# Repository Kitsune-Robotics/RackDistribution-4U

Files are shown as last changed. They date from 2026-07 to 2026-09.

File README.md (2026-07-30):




# RackDistribution-4U

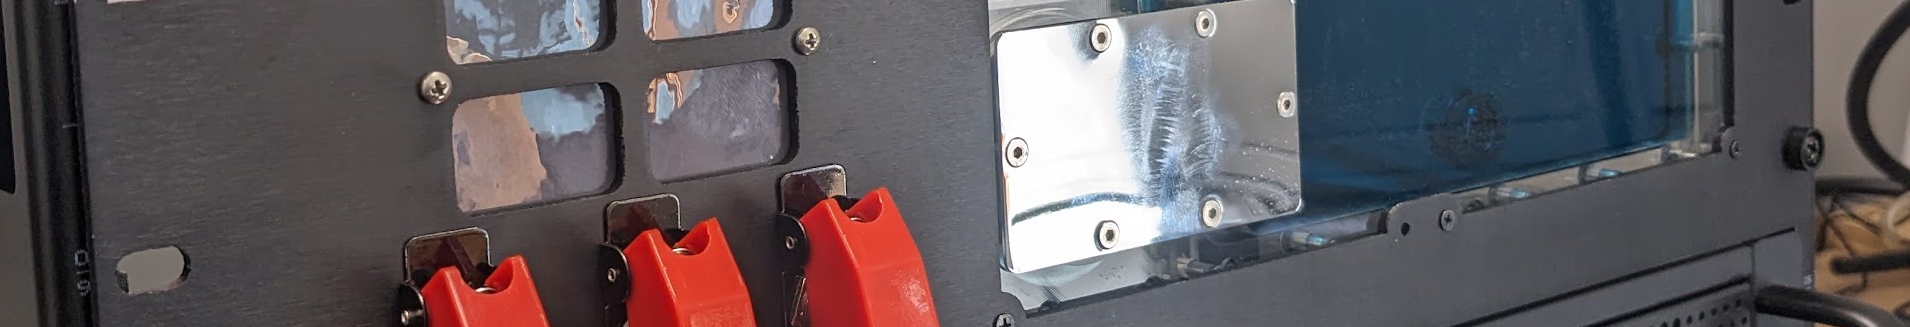
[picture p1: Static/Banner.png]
Banner


This repo contains all the firmware and hardware for the RackDistribution-4U.
If you're looking for the latest docs/builds, see our [Releases Page](https://github.com/Kitsune-Robotics/RackDistribution-4U/releases).

# Getting Started

First, clone this repo (and optionally checkout a branch)

```shell
git clone https://github.com/Kitsune-Robotics/RackDistribution-4U.git
cd RackDistribution-4U
```

# Init Submodules

Some libraries and resources are included as submodules, run the following
command to initialize them before opening the main sch

(If you get a missing library error, make sure to do this)

```shell
git submodule update --init --recursive
```

## Project Layout

If you want to use this project template for yourself, you can find it [here!](https://github.com/Kitsune-Robotics/Project-Template)

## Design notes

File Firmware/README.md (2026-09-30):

# Rack Distribution 4U firmware

Built with the [Pico SDK](https://github.com/raspberrypi/pico-sdk) for an RP2040.
FreeRTOS plus the WS2812 PIO driver for the light panel.

## To build

`pico_sdk_import.cmake` will pull the SDK if you don't already have `PICO_SDK_PATH`.

```shell
git submodule update --init Firmware/lib/FreeRTOS-Kernel
mkdir build
cd build
cmake ..
make
```

## To load

The running firmware is a composite USB device: RackDistribution HID (`1209:0001`), CDC, and a `RACKDIST` drive. Copy a UF2 onto that drive to update, or:

From the build directory:

```shell
../aquacomputer/pico-load rack_distribution.uf2
```

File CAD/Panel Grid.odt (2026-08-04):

STANDBY | COOLDOWN
A LITTLE HOT | CONTROL
LOW COOLANT | LOW PUMP SPEED
LOW FLOW | LOW FAN SPEED

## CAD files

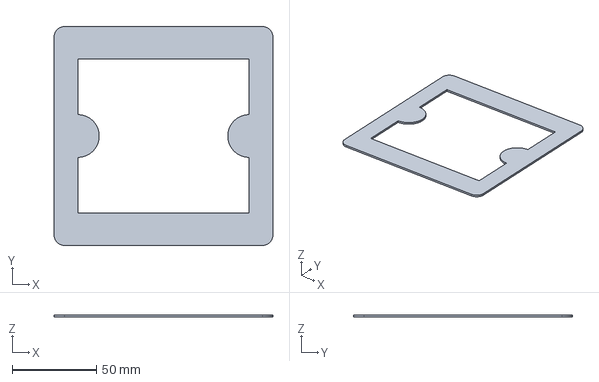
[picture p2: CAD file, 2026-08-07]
CAD/Solder Stencil.FCStd
130.0 x 130.0 x 1.40 mm

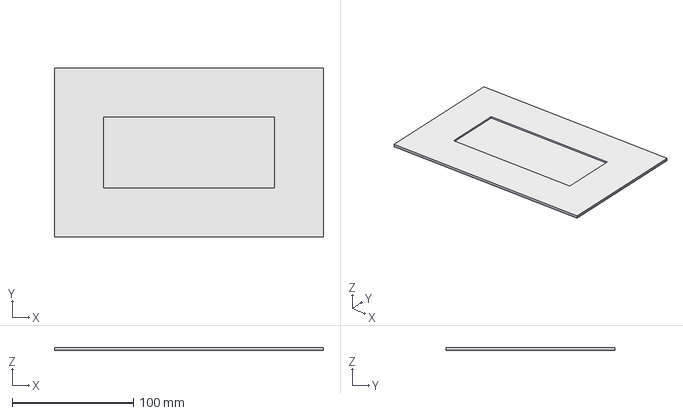
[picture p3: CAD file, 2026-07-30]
Hardware/LightPanel/Stencils/SolderMaskStencil.FCStd
222.2 x 139.7 x 2.60 mm

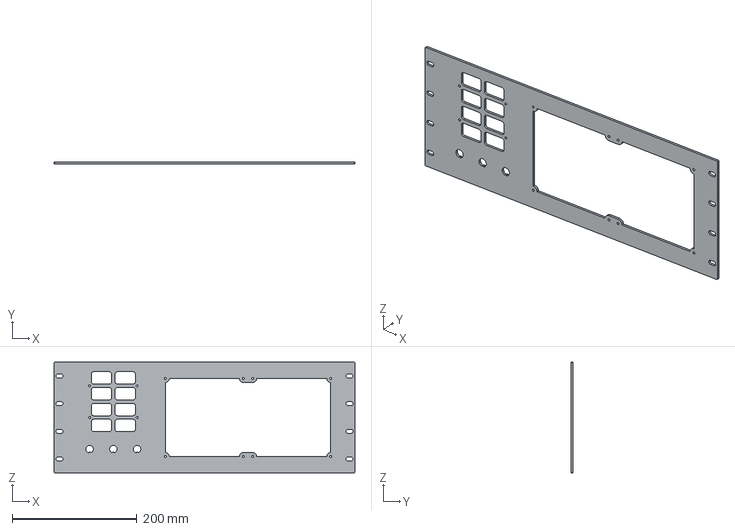
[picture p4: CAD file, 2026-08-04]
CAD/WaterCoolingRack-Sheet Metal.step
482.5 x 3.18 x 177.8 mm

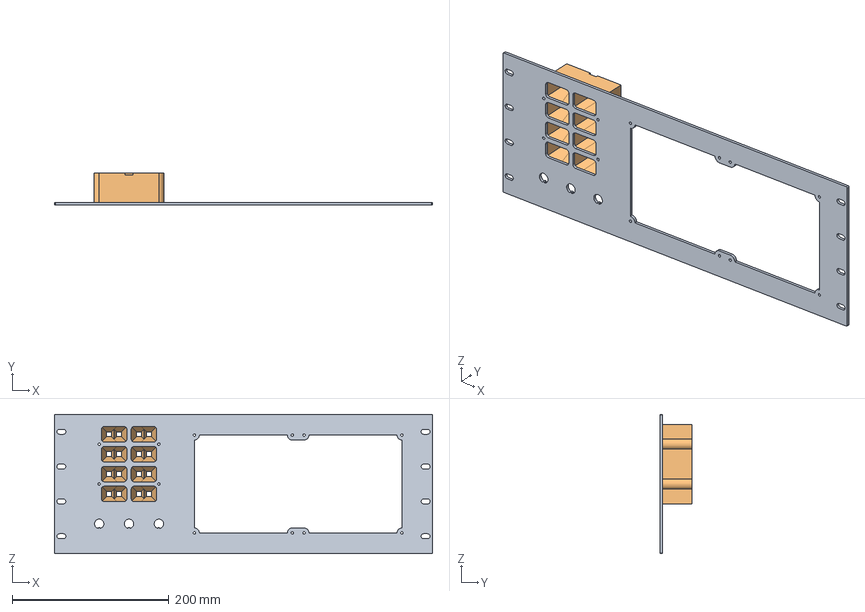
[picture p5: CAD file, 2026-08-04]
CAD/WaterCoolingRack.FCStd
482.5 x 41.3 x 177.8 mm
Sheet Metal
Light Gaurd

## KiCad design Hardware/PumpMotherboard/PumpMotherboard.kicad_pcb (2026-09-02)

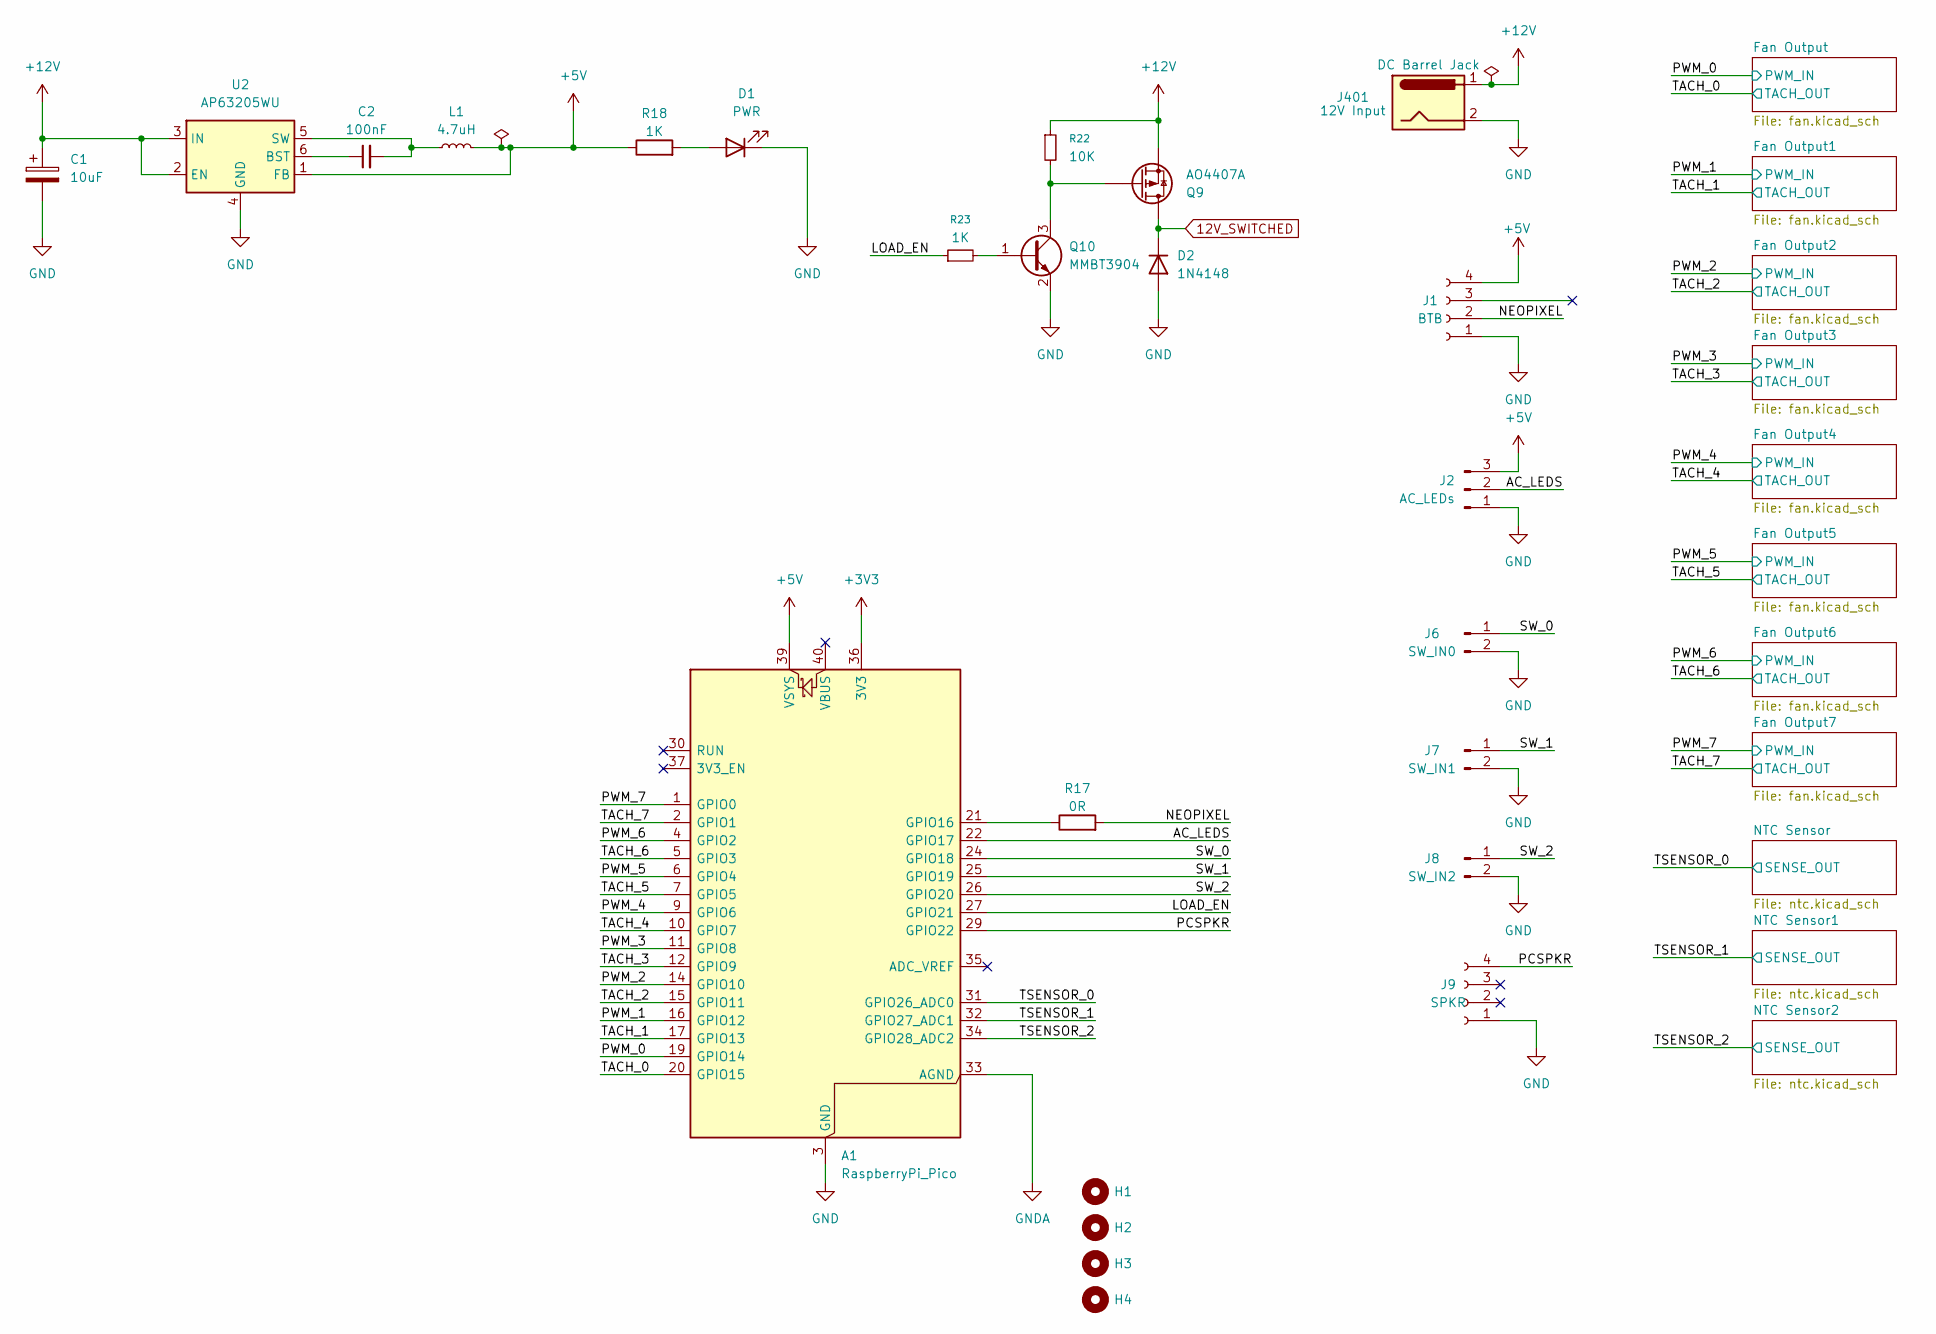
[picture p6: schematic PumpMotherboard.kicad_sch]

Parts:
A1: RaspberryPi_Pico; RaspberryPi_Pico_Common_SMD
C1: 10uF; CP_Elec_4x3
C2: 100nF; C_0805_2012Metric
D1: PWR; LED_0805_2012Metric
D2: 1N4148; D_DO-35_SOD27_P7.62mm_Horizontal
H1, H2, H3, H4: MountingHole; MountingHole_4.3mm_M4
J1: BTB; PinSocket_1x04_P2.54mm_Vertical
J2: AC_LEDs; JST_XH_B3B-XH-A_1x03_P2.50mm_Vertical
J6: SW_IN0; JST_XH_B2B-XH-A_1x02_P2.50mm_Vertical
J7: SW_IN1; JST_XH_B2B-XH-A_1x02_P2.50mm_Vertical
J8: SW_IN2; JST_XH_B2B-XH-A_1x02_P2.50mm_Vertical
J9: SPKR; PinHeader_1x04_P2.54mm_Vertical
J401: 12V Input; BarrelJack_GCT_DCJ200-10-A_Horizontal
L1: 4.7uH; L_APV_ANR4012; LCSC# C467061
Q9: AO4407A; SOIC-8_5.3x5.3mm_P1.27mm
Q10: MMBT3904; SOT-23
R17: 0R; R_0805_2012Metric
R18, R23: 1K; R_0805_2012Metric
R22: 10K; R_0805_2012Metric
U2: AP63205WU; TSOT-23-6; LCSC# C2071056

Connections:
12V_SWITCHED: D2.1 (K), Q9.5 (D), Q9.6 (D), Q9.7 (D), Q9.8 (D); also elsewhere on the board
+3V3: A1.36 (3V3); also elsewhere on the board
+5V: A1.39 (VSYS), J1.4, J2.3, L1.2, R18.1, U2.1 (FB)
+12V: C1.1, J401.1, Q9.1 (S), Q9.2 (S), Q9.3 (S), R22.1, U2.2 (EN), U2.3 (IN)
/AC_LEDS: A1.22 (GPIO17), J2.2
/LOAD_EN: A1.27 (GPIO21), R23.1
/NEOPIXEL: J1.2, R17.2
/PCSPKR: A1.29 (GPIO22), J9.4
/PWM_0: A1.19 (GPIO14); also elsewhere on the board
/PWM_1: A1.16 (GPIO12); also elsewhere on the board
/PWM_2: A1.14 (GPIO10); also elsewhere on the board
/PWM_3: A1.11 (GPIO8); also elsewhere on the board
/PWM_4: A1.9 (GPIO6); also elsewhere on the board
/PWM_5: A1.6 (GPIO4); also elsewhere on the board
/PWM_6: A1.4 (GPIO2); also elsewhere on the board
/PWM_7: A1.1 (GPIO0); also elsewhere on the board
/SW_0: A1.24 (GPIO18), J6.1
/SW_1: A1.25 (GPIO19), J7.1
/SW_2: A1.26 (GPIO20), J8.1
/TACH_0: A1.20 (GPIO15); also elsewhere on the board
/TACH_1: A1.17 (GPIO13); also elsewhere on the board
/TACH_2: A1.15 (GPIO11); also elsewhere on the board
/TACH_3: A1.12 (GPIO9); also elsewhere on the board
/TACH_4: A1.10 (GPIO7); also elsewhere on the board
/TACH_5: A1.7 (GPIO5); also elsewhere on the board
/TACH_6: A1.5 (GPIO3); also elsewhere on the board
/TACH_7: A1.2 (GPIO1); also elsewhere on the board
/TSENSOR_0: A1.31 (GPIO26_ADC0); also elsewhere on the board
/TSENSOR_1: A1.32 (GPIO27_ADC1); also elsewhere on the board
/TSENSOR_2: A1.34 (GPIO28_ADC2); also elsewhere on the board
GND: A1.3 (GND), A1.8 (GND), A1.13 (GND), A1.18 (GND), A1.23 (GND), A1.28 (GND), A1.38 (GND), C1.2, D1.1 (K), D2.2 (A), J1.1, J2.1, J6.2, J7.2, J8.2, J9.1, J401.2, Q10.2 (E), U2.4 (GND); also elsewhere on the board
GNDA: A1.33 (AGND); also elsewhere on the board
unnamed: A1.21 (GPIO16), R17.1
unnamed: D1.2 (A), R18.2
unnamed: Q10.1 (B), R23.2
unnamed: Q9.4 (G), Q10.3 (C), R22.2
unnamed: C2.1, U2.6 (BST)
unnamed: C2.2, L1.1, U2.5 (SW)

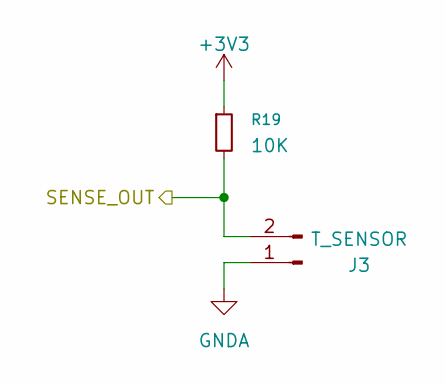
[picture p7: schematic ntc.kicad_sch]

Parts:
J3: T_SENSOR; PinHeader_1x02_P2.54mm_Vertical
R19: 10K; R_0805_2012Metric

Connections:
+3V3: R19.1; also elsewhere on the board
/TSENSOR_0: J3.2, R19.2; also elsewhere on the board
GNDA: J3.1; also elsewhere on the board

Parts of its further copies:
J4, J5: T_SENSOR; PinHeader_1x02_P2.54mm_Vertical
R20, R21: 10K; R_0805_2012Metric

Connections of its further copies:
+3V3: R20.1, R21.1; also elsewhere on the board
/TSENSOR_1: J4.2, R20.2; also elsewhere on the board
/TSENSOR_2: J5.2, R21.2; also elsewhere on the board
GNDA: J4.1, J5.1; also elsewhere on the board

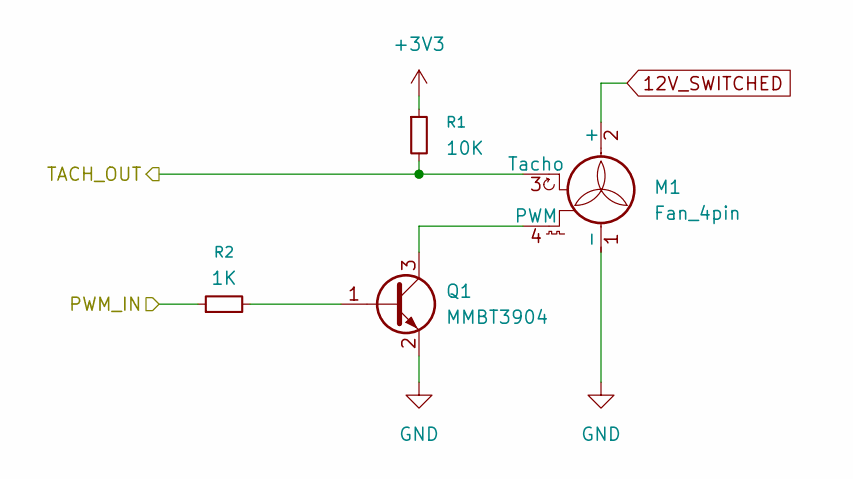
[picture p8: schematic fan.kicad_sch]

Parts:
M1: Fan_4pin; FanPinHeader_1x04_P2.54mm_Vertical; LCSC# C240840
Q1: MMBT3904; SOT-23
R1: 10K; R_0805_2012Metric
R2: 1K; R_0805_2012Metric

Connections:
12V_SWITCHED: M1.2 (+); also elsewhere on the board
+3V3: R1.1; also elsewhere on the board
/PWM_0: R2.1; also elsewhere on the board
/TACH_0: M1.3 (Tacho), R1.2; also elsewhere on the board
GND: M1.1 (-), Q1.2 (E); also elsewhere on the board
unnamed: M1.4 (PWM), Q1.3 (C)
unnamed: Q1.1 (B), R2.2

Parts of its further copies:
M2, M3, M4, M5, M6, M7, M8: Fan_4pin; FanPinHeader_1x04_P2.54mm_Vertical; LCSC# C240840
Q2, Q3, Q4, Q5, Q6, Q7, Q8: MMBT3904; SOT-23
R3, R5, R7, R9, R11, R13, R15: 1K; R_0805_2012Metric
R4, R6, R8, R10, R12, R14, R16: 10K; R_0805_2012Metric

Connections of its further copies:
12V_SWITCHED: M2.2 (+), M3.2 (+), M4.2 (+), M5.2 (+), M6.2 (+), M7.2 (+), M8.2 (+); also elsewhere on the board
+3V3: R4.1, R6.1, R8.1, R10.1, R12.1, R14.1, R16.1; also elsewhere on the board
/PWM_1: R3.1; also elsewhere on the board
/PWM_2: R5.1; also elsewhere on the board
/PWM_3: R7.1; also elsewhere on the board
/PWM_4: R9.1; also elsewhere on the board
/PWM_5: R11.1; also elsewhere on the board
/PWM_6: R13.1; also elsewhere on the board
/PWM_7: R15.1; also elsewhere on the board
/TACH_1: M2.3 (Tacho), R4.2; also elsewhere on the board
/TACH_2: M3.3 (Tacho), R6.2; also elsewhere on the board
/TACH_3: M4.3 (Tacho), R8.2; also elsewhere on the board
/TACH_4: M5.3 (Tacho), R10.2; also elsewhere on the board
/TACH_5: M6.3 (Tacho), R12.2; also elsewhere on the board
/TACH_6: M7.3 (Tacho), R14.2; also elsewhere on the board
/TACH_7: M8.3 (Tacho), R16.2; also elsewhere on the board
GND: M2.1 (-), M3.1 (-), M4.1 (-), M5.1 (-), M6.1 (-), M7.1 (-), M8.1 (-), Q2.2 (E), Q3.2 (E), Q4.2 (E), Q5.2 (E), Q6.2 (E), Q7.2 (E), Q8.2 (E); also elsewhere on the board
unnamed: M2.4 (PWM), Q2.3 (C)
unnamed: M3.4 (PWM), Q3.3 (C)
unnamed: M4.4 (PWM), Q4.3 (C)
unnamed: M5.4 (PWM), Q5.3 (C)
unnamed: M6.4 (PWM), Q6.3 (C)
unnamed: M7.4 (PWM), Q7.3 (C)
unnamed: M8.4 (PWM), Q8.3 (C)
unnamed: Q2.1 (B), R3.2
unnamed: Q3.1 (B), R5.2
unnamed: Q4.1 (B), R7.2
unnamed: Q5.1 (B), R9.2
unnamed: Q6.1 (B), R11.2
unnamed: Q7.1 (B), R13.2
unnamed: Q8.1 (B), R15.2

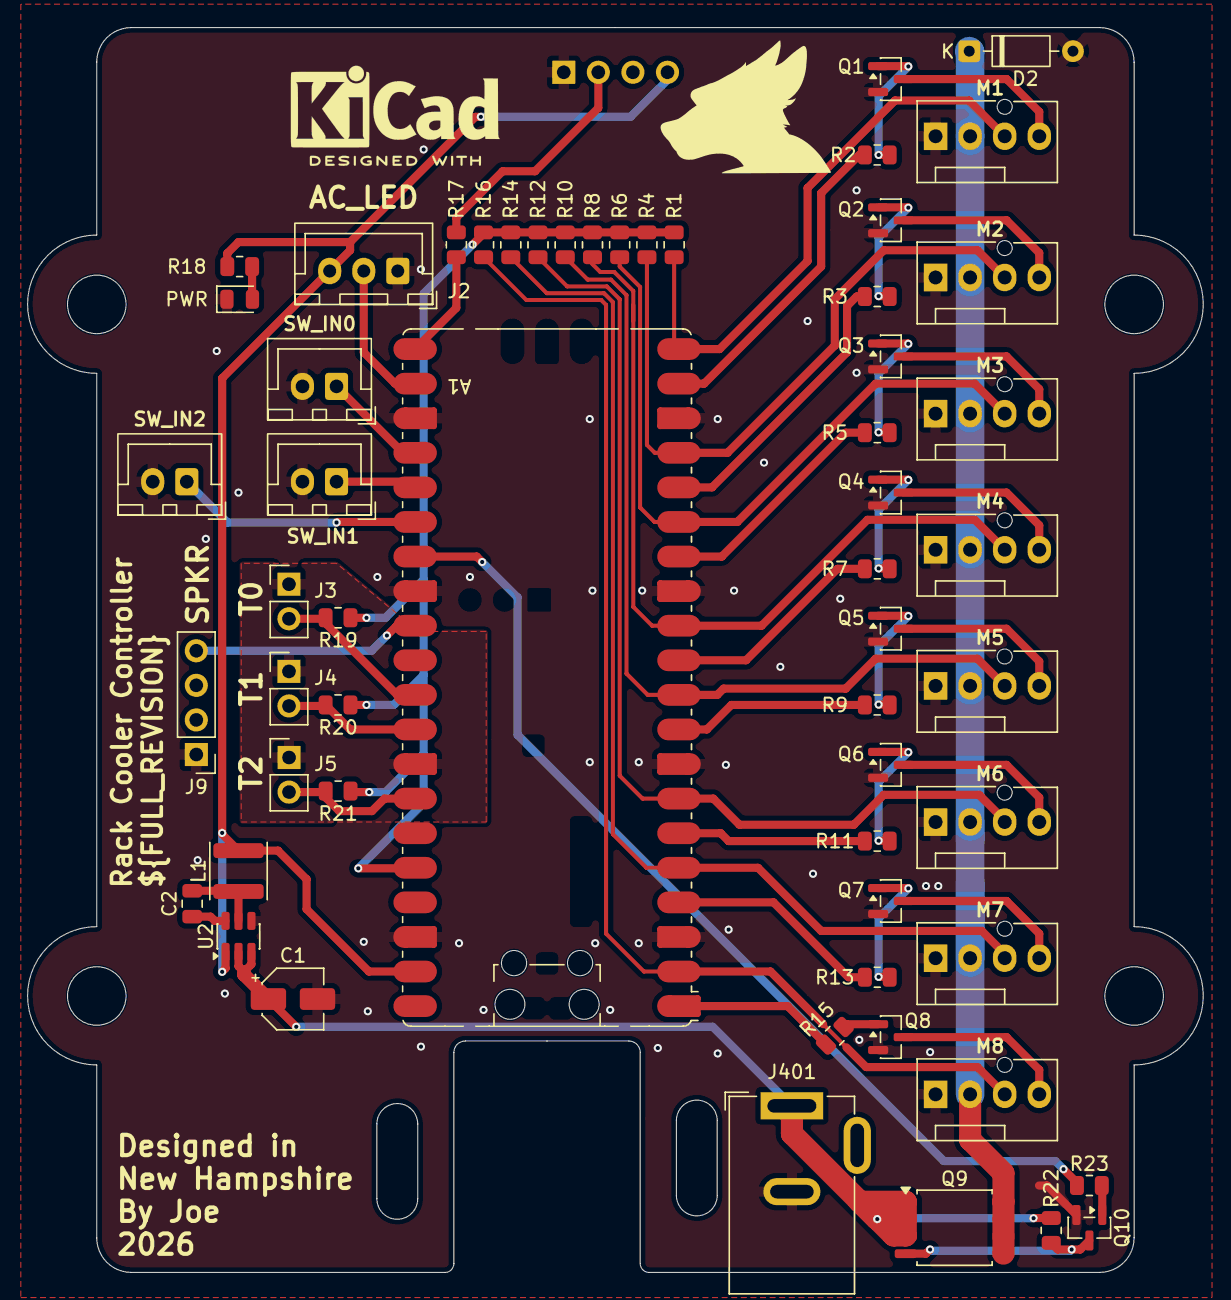
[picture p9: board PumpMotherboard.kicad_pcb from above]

Board: 2 copper layers, 86.4 x 91.4 mm, 62 parts (1 on the bottom side), 54 nets.

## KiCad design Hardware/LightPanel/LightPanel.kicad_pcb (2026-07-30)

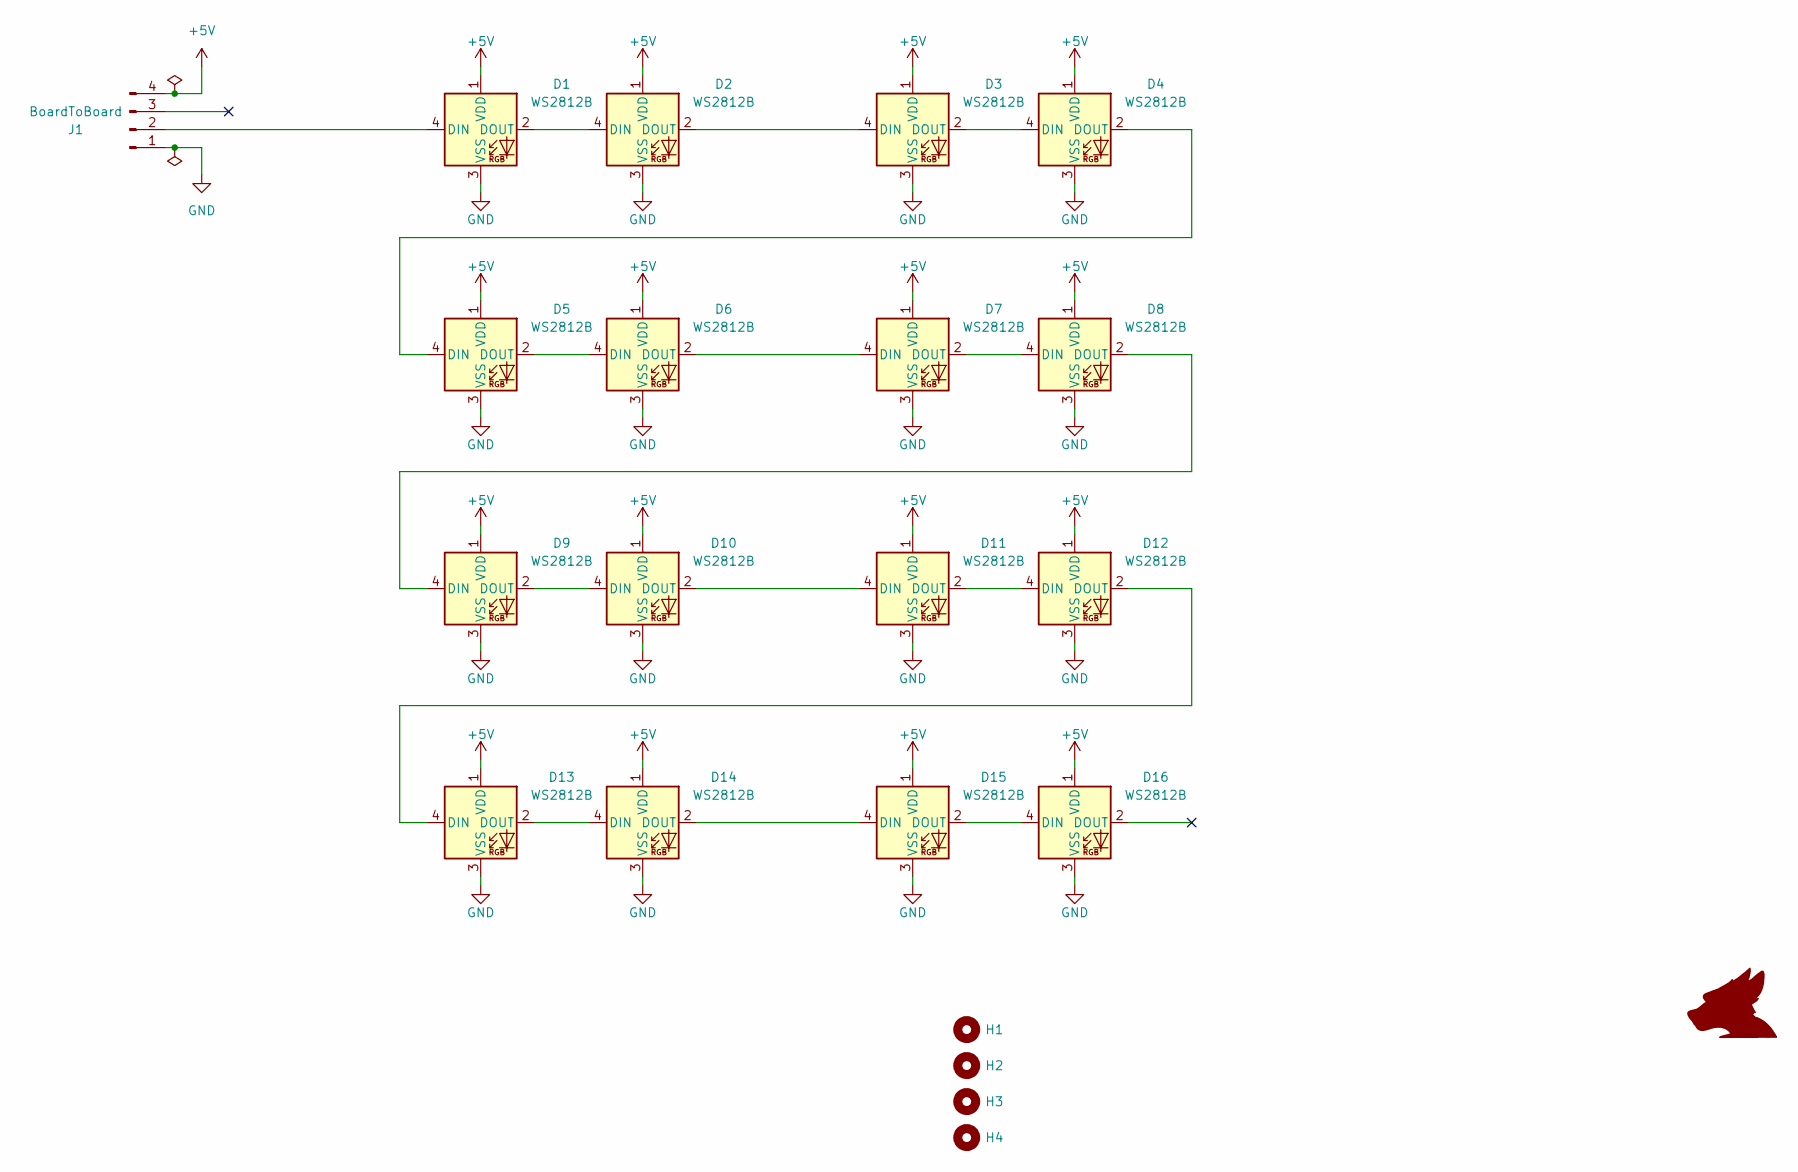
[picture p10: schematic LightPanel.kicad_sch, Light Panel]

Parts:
D1, D2, D3, D4, D5, D6, D7, D8, D9, D10, D11, D12, D13, D14, D15, D16: WS2812B; LED_WS2812B_PLCC4_5.0x5.0mm_P3.2mm; LCSC# C52917433
H1, H2, H3, H4: MountingHole; MountingHole_4.3mm_M4
J1: BoardToBoard; PinHeader_1x04_P2.54mm_Vertical

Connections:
+5V: D1.1 (VDD), D2.1 (VDD), D3.1 (VDD), D4.1 (VDD), D5.1 (VDD), D6.1 (VDD), D7.1 (VDD), D8.1 (VDD), D9.1 (VDD), D10.1 (VDD), D11.1 (VDD), D12.1 (VDD), D13.1 (VDD), D14.1 (VDD), D15.1 (VDD), D16.1 (VDD), J1.4
GND: D1.3 (VSS), D2.3 (VSS), D3.3 (VSS), D4.3 (VSS), D5.3 (VSS), D6.3 (VSS), D7.3 (VSS), D8.3 (VSS), D9.3 (VSS), D10.3 (VSS), D11.3 (VSS), D12.3 (VSS), D13.3 (VSS), D14.3 (VSS), D15.3 (VSS), D16.3 (VSS), J1.1
unnamed: D1.4 (DIN), J1.2
unnamed: D1.2 (DOUT), D2.4 (DIN)
unnamed: D2.2 (DOUT), D3.4 (DIN)
unnamed: D3.2 (DOUT), D4.4 (DIN)
unnamed: D4.2 (DOUT), D5.4 (DIN)
unnamed: D5.2 (DOUT), D6.4 (DIN)
unnamed: D6.2 (DOUT), D7.4 (DIN)
unnamed: D7.2 (DOUT), D8.4 (DIN)
unnamed: D8.2 (DOUT), D9.4 (DIN)
unnamed: D9.2 (DOUT), D10.4 (DIN)
unnamed: D10.2 (DOUT), D11.4 (DIN)
unnamed: D11.2 (DOUT), D12.4 (DIN)
unnamed: D12.2 (DOUT), D13.4 (DIN)
unnamed: D13.2 (DOUT), D14.4 (DIN)
unnamed: D14.2 (DOUT), D15.4 (DIN)
unnamed: D15.2 (DOUT), D16.4 (DIN)

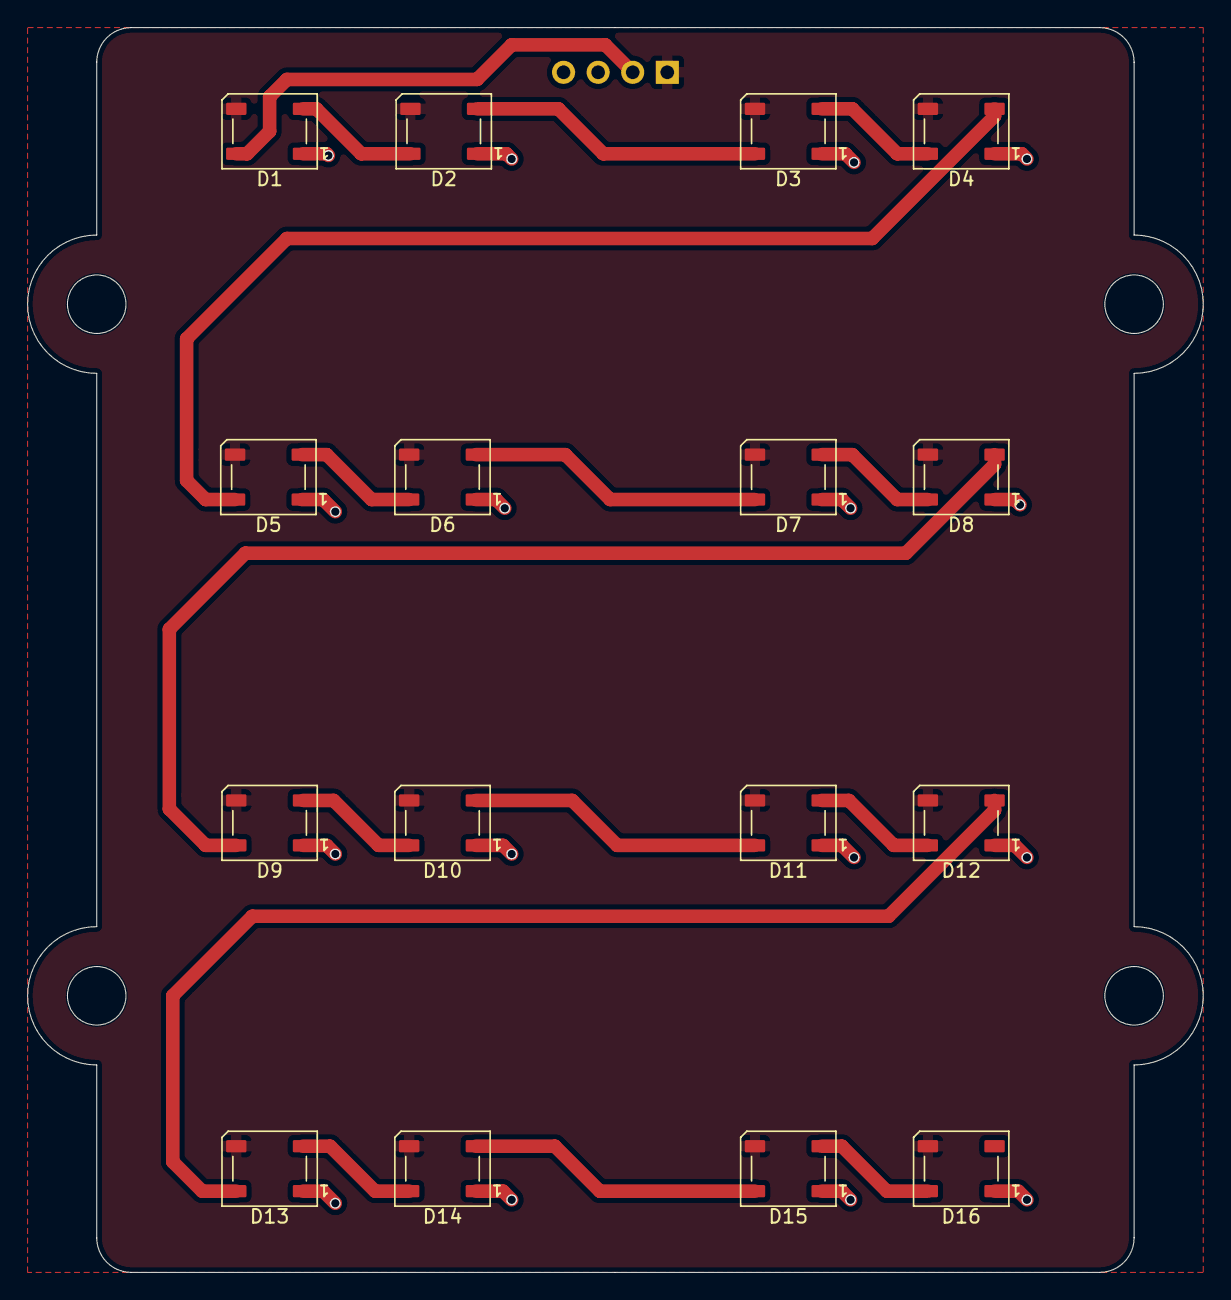
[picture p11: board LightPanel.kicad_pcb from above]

Board: 2 copper layers, 86.4 x 91.4 mm, 21 parts (1 on the bottom side), 18 nets.

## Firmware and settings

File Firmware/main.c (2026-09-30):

#include "FreeRTOS.h"
#include "analog.h"
#include "hid.h"
#include "fans.h"
#include "indicators.h"
#include "neopixel_ws2812.h"
#include "pico/stdio.h"
#include "pindefs.h"
#include "states.h"
#include "task.h"

static void led_task(void *pvParameters) {
  (void)pvParameters;

  static neopixel_ws2812_t strip;
  static neopixel_ws2812_t ac;

  neopixel_ws2812_max_brightness = 64;
  neopixel_ws2812_init(&strip, pio0, NEOPIXEL_PIN, NEOPIXEL_FREQ_HZ, false,
                       NEOPIXEL_NUM_PIXELS);
  neopixel_ws2812_init(&ac, pio0, AC_LEDS_PIN, NEOPIXEL_FREQ_HZ, false,
                       AC_LEDS_NUM_PIXELS);

  while (true) {
    TickType_t now = xTaskGetTickCount();
    indicators_flush(&strip, (uint32_t)now);
    if (state_get() == STATE_RUN) {
      neopixel_ws2812_put_rgb(&ac, 220, 220, 220);
    } else {
      neopixel_ws2812_put_rgb(&ac, 10, 0, 0);
    }
    vTaskDelay(pdMS_TO_TICKS(25));
  }
}

int main(void) {
  stdio_init_all();

  if (xTaskCreate(state_task, "state", 512, NULL, 3, NULL) != pdPASS) {
    vApplicationMallocFailedHook();
  }
  if (xTaskCreate(led_task, "led", 512, NULL, 1, NULL) != pdPASS) {
    vApplicationMallocFailedHook();
  }
  if (xTaskCreate(analog_task, "analog", 512, NULL, 2, NULL) != pdPASS) {
    vApplicationMallocFailedHook();
  }
  if (xTaskCreate(fans_task, "fans", 512, NULL, 2, NULL) != pdPASS) {
    vApplicationMallocFailedHook();
  }

  if (xTaskCreate(hid_task, "hid", 512, NULL, 2, NULL) != pdPASS) {
    vApplicationMallocFailedHook();
  }

  vTaskStartScheduler();
  vApplicationMallocFailedHook();

  while (true) {
  }
}

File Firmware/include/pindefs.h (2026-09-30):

#pragma once

// Fan PWM / tach (GPIO)
#define PWM_7_PIN 0
#define TACH_7_PIN 1
#define PWM_6_PIN 2
#define TACH_6_PIN 3
#define PWM_5_PIN 4
#define TACH_5_PIN 5
#define PWM_4_PIN 6
#define TACH_4_PIN 7
#define PWM_3_PIN 8
#define TACH_3_PIN 9
#define PWM_2_PIN 10
#define TACH_2_PIN 11
#define PWM_1_PIN 12
#define TACH_1_PIN 13
#define PWM_0_PIN 14
#define TACH_0_PIN 15

// Panel
#define NEOPIXEL_PIN 16
#define NEOPIXEL_NUM_PIXELS 16
#define NEOPIXEL_FREQ_HZ 800000.0f
#define AC_LEDS_PIN 17
#define AC_LEDS_NUM_PIXELS 50 // idk the exact length

// Switches
#define SW_0_PIN 18 // inhibit
#define SW_1_PIN 19 // max cooling
#define SW_2_PIN 20 // mute
#define SW_INHIBIT_PIN SW_0_PIN
#define SW_MAX_COOL_PIN SW_1_PIN
#define SW_MUTE_PIN SW_2_PIN

#define LOAD_EN_PIN 21
#define PCSPKR_PIN 22
#define USB_VBUS_PIN 24 /* Pico module VBUS divider*/

// Temperature (GPIO / ADC channel)
#define TSENSOR_0_PIN 26 /* coolant */
#define TSENSOR_0_ADC_CH 0
#define TSENSOR_1_PIN 27 /* air */
#define TSENSOR_1_ADC_CH 1
#define TSENSOR_2_PIN 28 /* exhaust (optional) */
#define TSENSOR_2_ADC_CH 2

#define TSENSOR_PULLUP_OHMS 10000.0f
#define NTC_R25_OHMS 10000.0f
#define NTC_BETA 3950.0f
#define NTC_SHORT_RAW 32
#define NTC_OPEN_RAW 3900 /* ~200k / -30 C; unplugged sits near the 3V3 rail */

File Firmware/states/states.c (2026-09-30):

#include "state_internal.h"

#include "analog.h"
#include "fans.h"
#include "hardware/gpio.h"
#include "indicators.h"
#include "parameters.h"
#include "pindefs.h"
#include "speaker.h"
#include "switches.h"
#include "usb_vbus.h"

#include <stdbool.h>

static volatile system_state_t g_state = STATE_INIT;
static TickType_t g_entered;

typedef struct {
  void (*tick)(TickType_t now);
  void (*entry)(void);
} state_ops_t;

static const state_ops_t k_ops[] = {
    [STATE_INIT] = {state_init_tick, state_init_entry},
    [STATE_STANDBY] = {state_standby_tick, state_standby_entry},
    [STATE_COOLDOWN] = {state_cooldown_tick, state_cooldown_entry},
    [STATE_RUN] = {state_run_tick, state_run_entry},
};

system_state_t state_get(void) { return g_state; }

TickType_t state_entered(void) { return g_entered; }

static void load_apply(void) {
  gpio_put(LOAD_EN_PIN, g_state != STATE_STANDBY && !switches_inhibit());
}

void state_goto(system_state_t next) {
  g_state = next;
  g_entered = xTaskGetTickCount();
  load_apply();
  indicators_clear();
  k_ops[next].entry();
}

static void state_update_warnings(void) {
  static bool a_little_hot;

  if (fans_pump_low()) {
    indicator_fast_flash(&g_indicators.low_pump_speed, COLOR_RED);
  } else if (g_state != STATE_INIT) {
    indicator_off(&g_indicators.low_pump_speed);
  }

  if (fans_fan_low()) {
    indicator_fast_flash(&g_indicators.low_fan_speed, COLOR_RED);
  } else if (g_state != STATE_INIT) {
    indicator_off(&g_indicators.low_fan_speed);
  }

  if (g_state == STATE_INIT) {
    return;
  }

  const float t = analog_control_c();
  const float hot = analog_air_c() + A_LITTLE_HOT_ABOVE_AIR_C;
  const bool was_hot = a_little_hot;

  if (t > hot + A_LITTLE_HOT_HISTERESIS_C) {
    a_little_hot = true;
  } else if (t < hot - A_LITTLE_HOT_HISTERESIS_C) {
    a_little_hot = false;
  }

  if (a_little_hot) {
    indicator_flash(&g_indicators.a_little_hot, COLOR_RED);
    if (!was_hot) {
      speaker_beep();
    }
  } else {
    indicator_off(&g_indicators.a_little_hot);
  }
}

void state_task(void *pvParameters) {
  (void)pvParameters;

  gpio_init(LOAD_EN_PIN);
  gpio_put(LOAD_EN_PIN, 0);
  gpio_set_dir(LOAD_EN_PIN, GPIO_OUT);
  switches_init();
  usb_vbus_init();
  speaker_init();
  speaker_beep();

  state_goto(STATE_INIT);

  while (true) {
    switches_tick();
    load_apply();
    k_ops[g_state].tick(xTaskGetTickCount());
    state_update_warnings();
    speaker_tick(g_state != STATE_INIT && indicators_fast_flashing_red());
    vTaskDelay(pdMS_TO_TICKS(25));
  }
}

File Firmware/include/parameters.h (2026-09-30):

#pragma once

// Fans
#define FAN_PWM_HZ 25000.0f
#define FAN_TACH_PPR 2
#define FAN_RPM_WINDOW_MS 200 // Window to look for pulses in
#define FAN_RPM_STALL_MS 500 // Timeout for seeing an edge
#define FAN_RPM_LOW_MS 2000 // Time to wait before warning (hopefully fixes random chirps)

// Temperature
#define A_LITTLE_HOT_ABOVE_AIR_C 6.0f
#define A_LITTLE_HOT_HISTERESIS_C 0.25f
#define COOLDOWN_COLD_ABOVE_AIR_C 6.0f
#define TSENSOR0_OFFSET_C 1.5f /* coolant */
#define TSENSOR1_OFFSET_C -1.5f /* air */
#define TSENSOR2_OFFSET_C 0.0f /* exhaust */
#define AMBIENT_FALLBACK_C 20.0f

// PC speaker
#define PCSPKR_HZ 2000.0f
#define PCSPKR_BEEP_MS 80
#define PCSPKR_GAP_MS 80
#define PCSPKR_PERIOD_MS 1000

// 1 to enable
#define ENABLE_UF2_LOADER 1

// State configs
#define STATE_INIT_MS 4000
#define STATE_USB_LOST_MS 5000
#define STATE_COOLDOWN_COLD_MS 10000

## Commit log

2026-07-30 Import all from prototype project
    [LightPanel.kicad_pcb, LightPanel.kicad_sch, SolderMaskStencil.FCStd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]
2026-07-30 Add libraries, 3d models and other bits
    [LightPanel.kicad_pcb, WaterCoolingRack.FCStd]
2026-07-30 Move and fix CI path
    [LightPanel.kicad_pcb, LightPanel.kicad_sch, SolderMaskStencil.FCStd]
2026-07-30 Fix ERC
    [LightPanel.kicad_sch]
2026-07-30 Fix DRC
    [LightPanel.kicad_pcb]
2026-07-30 Tweak CPL and BOM to match JLCPCB format better
2026-07-31 Cad bump
    [PumpMotherboard.kicad_pcb, PumpMotherboard.kicad_sch, WaterCoolingRack.FCStd]
2026-08-04 Fix the orientation of the switches
    [WaterCoolingRack.FCStd]
2026-08-04 Add more bits to motherboard/controller panel
    [PumpMotherboard.kicad_pcb, PumpMotherboard.kicad_sch, WaterCoolingRack-Sheet Metal.step]
2026-08-04 Replicate plugin is being a pain
    [PumpMotherboard.kicad_pcb, PumpMotherboard.kicad_sch, fan.kicad_sch]
2026-08-05 Add LCSC part num
    [fan.kicad_sch]
2026-08-05 Add tsensors, misc bits
    [PumpMotherboard.kicad_pcb, PumpMotherboard.kicad_sch, ntc.kicad_sch]
2026-08-05 Fix DRC and ERC and add AGND
    [PumpMotherboard.kicad_pcb, PumpMotherboard.kicad_sch, ntc.kicad_sch]
2026-08-05 Add SW inputs
    [PumpMotherboard.kicad_pcb, PumpMotherboard.kicad_sch]
2026-08-07 Add solder stencil
    [Solder Stencil.FCStd]
2026-08-19 Thicken 12V trace
    [PumpMotherboard.kicad_pcb]
2026-08-27 Add 12v power switching
    [PumpMotherboard.kicad_pcb, PumpMotherboard.kicad_sch, fan.kicad_sch]
2026-08-27 Add flyback protection
    [PumpMotherboard.kicad_pcb, PumpMotherboard.kicad_sch]
2026-08-28 Tweak board a little
    [PumpMotherboard.kicad_pcb]
2026-08-28 Add PCSPKR output
    [PumpMotherboard.kicad_pcb, PumpMotherboard.kicad_sch]
2026-08-28 Split dual boards into a k10 matrix
2026-08-28 Tighten glob
2026-08-31 Add fan PIO and bits
2026-09-03 Move fan stuff to lib/fans
2026-09-04 Well i tried
    [PumpMotherboard.kicad_sch, fan.kicad_sch, ntc.kicad_sch]
2026-09-17 Add ambient to auto-scale fan curves
2026-09-18 Adjust calibration
2026-09-18 Tune fan curves
2026-09-21 Add switches
2026-09-21 adjust fan curves and disable uf2 mode
2026-09-22 Maybe fix a chirp bug
    [parameters.h]
